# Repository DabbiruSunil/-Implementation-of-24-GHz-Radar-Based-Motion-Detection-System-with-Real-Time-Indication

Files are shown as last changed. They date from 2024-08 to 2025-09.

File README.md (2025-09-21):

# 📡 24-GHz Radar-Based Motion Detection System with Real-Time Indication

This repository contains the design, development, and testing files for a **24-GHz radar-based motion detection system**, capable of detecting movement with high accuracy using real-time signal processing. The project integrates hardware (custom PCB with a 24-GHz radar module) and software (firmware, MATLAB analysis, and signal processing algorithms) into a complete working system.

---

## 📌 Project Overview

The objective of this project is to build a **precise motion detection system** leveraging a **24-GHz radar sensor**. The radar signals are captured, digitized, and processed in real time to provide immediate feedback when motion is detected.

### Hardware

* Custom PCB designed in **KiCad**.
* Integration of **24-GHz radar module**, **ADC**, **DAC**, and **DMA** for efficient data handling.
* Gerber files provided for fabrication.

### Software

* **Firmware** written in **PSoC Creator** for the Cypress PSoC 5LP microcontroller.
* State machine–based design for efficient real-time processing.
* **MATLAB scripts** for radar data analysis and Discrete Fourier Transform (DFT)–based signal evaluation.

---

## ✨ Features

* **High-frequency motion detection** at 24 GHz.
* **Custom PCB** with modular radar integration.
* **Real-time indication** of detected motion.
* **Efficient data processing pipeline** using DMA and microcontroller firmware.
* **MATLAB support** for offline data visualization and spectral analysis.

---

## 📂 Repository Contents

* **`24GHz-Radar for movement Detection.pptx`** – Presentation of design, implementation, and performance.
* **`Gerber files for PCB.zip`** – Fabrication files for the custom PCB.
* **`KiCad files for PCB.zip`** – Full KiCad project for PCB layout and schematic.
* **`PSoC_project.zip`** – Source code, configuration, and firmware project for PSoC Creator.

---

## 🛠️ Getting Started

### 🔧 Prerequisites

* [KiCad](https://www.kicad.org/) – For PCB design files.
* [PSoC Creator](https://www.cypress.com/products/psoc-creator-integrated-design-environment-ide) – To build and flash firmware onto the PSoC 5LP.
* [MATLAB](https://www.mathworks.com/products/matlab.html) – For radar data analysis and signal processing.
* PCB fabrication service – To manufacture the board from the Gerber files.

### ⚙️ Installation & Usage

#### 1. PCB Design

* Open KiCad project files.
* Review or modify the layout.
* Send **Gerber files** to a PCB manufacturer.

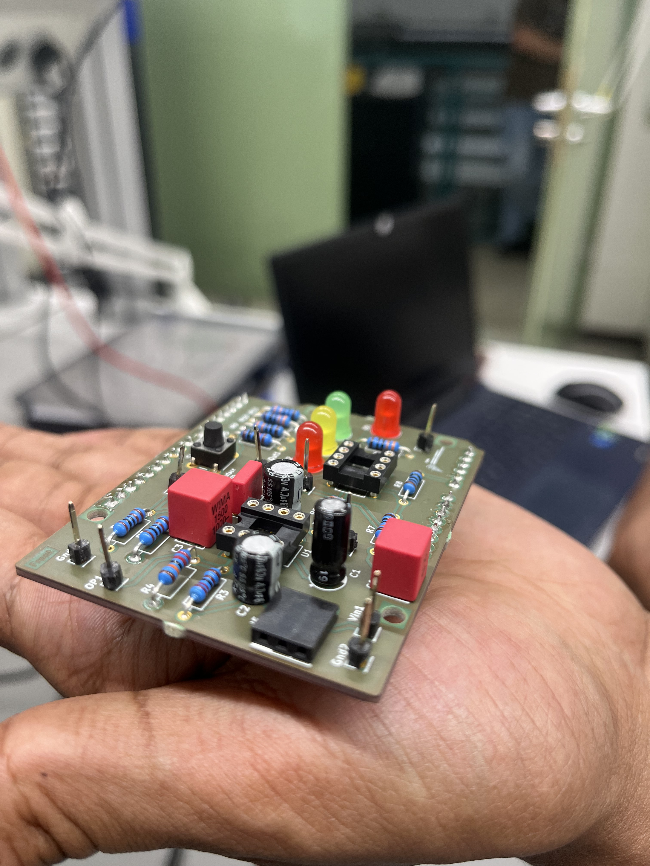
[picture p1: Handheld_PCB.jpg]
Handheld PCB
  

#### 2. Firmware Development

* Open the **PSoC project** in PSoC Creator.
* Compile and program the PSoC 5LP microcontroller.

#### 3. Signal Processing

* Use MATLAB scripts to process captured radar data.
* Perform **DFT analysis** for precise motion detection.

---

## 🧪 Testing & Validation

* Hardware validated through PCB prototypes.
* Firmware tested with real-time motion detection scenarios.
* MATLAB used to visualize motion profiles and confirm radar accuracy.

---

## 🤝 Contributing

Contributions are welcome! To propose improvements:

1. Fork this repository.
2. Create a feature branch.
3. Commit your changes.
4. Submit a pull request with details.

---

## 📜 License

MIT License – see [LICENSE](LICENSE) for details.

**Author:** Sunil Dabbiru

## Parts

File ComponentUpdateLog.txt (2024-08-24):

Last Modified Date & Time: 07/13/2024 11:51:06

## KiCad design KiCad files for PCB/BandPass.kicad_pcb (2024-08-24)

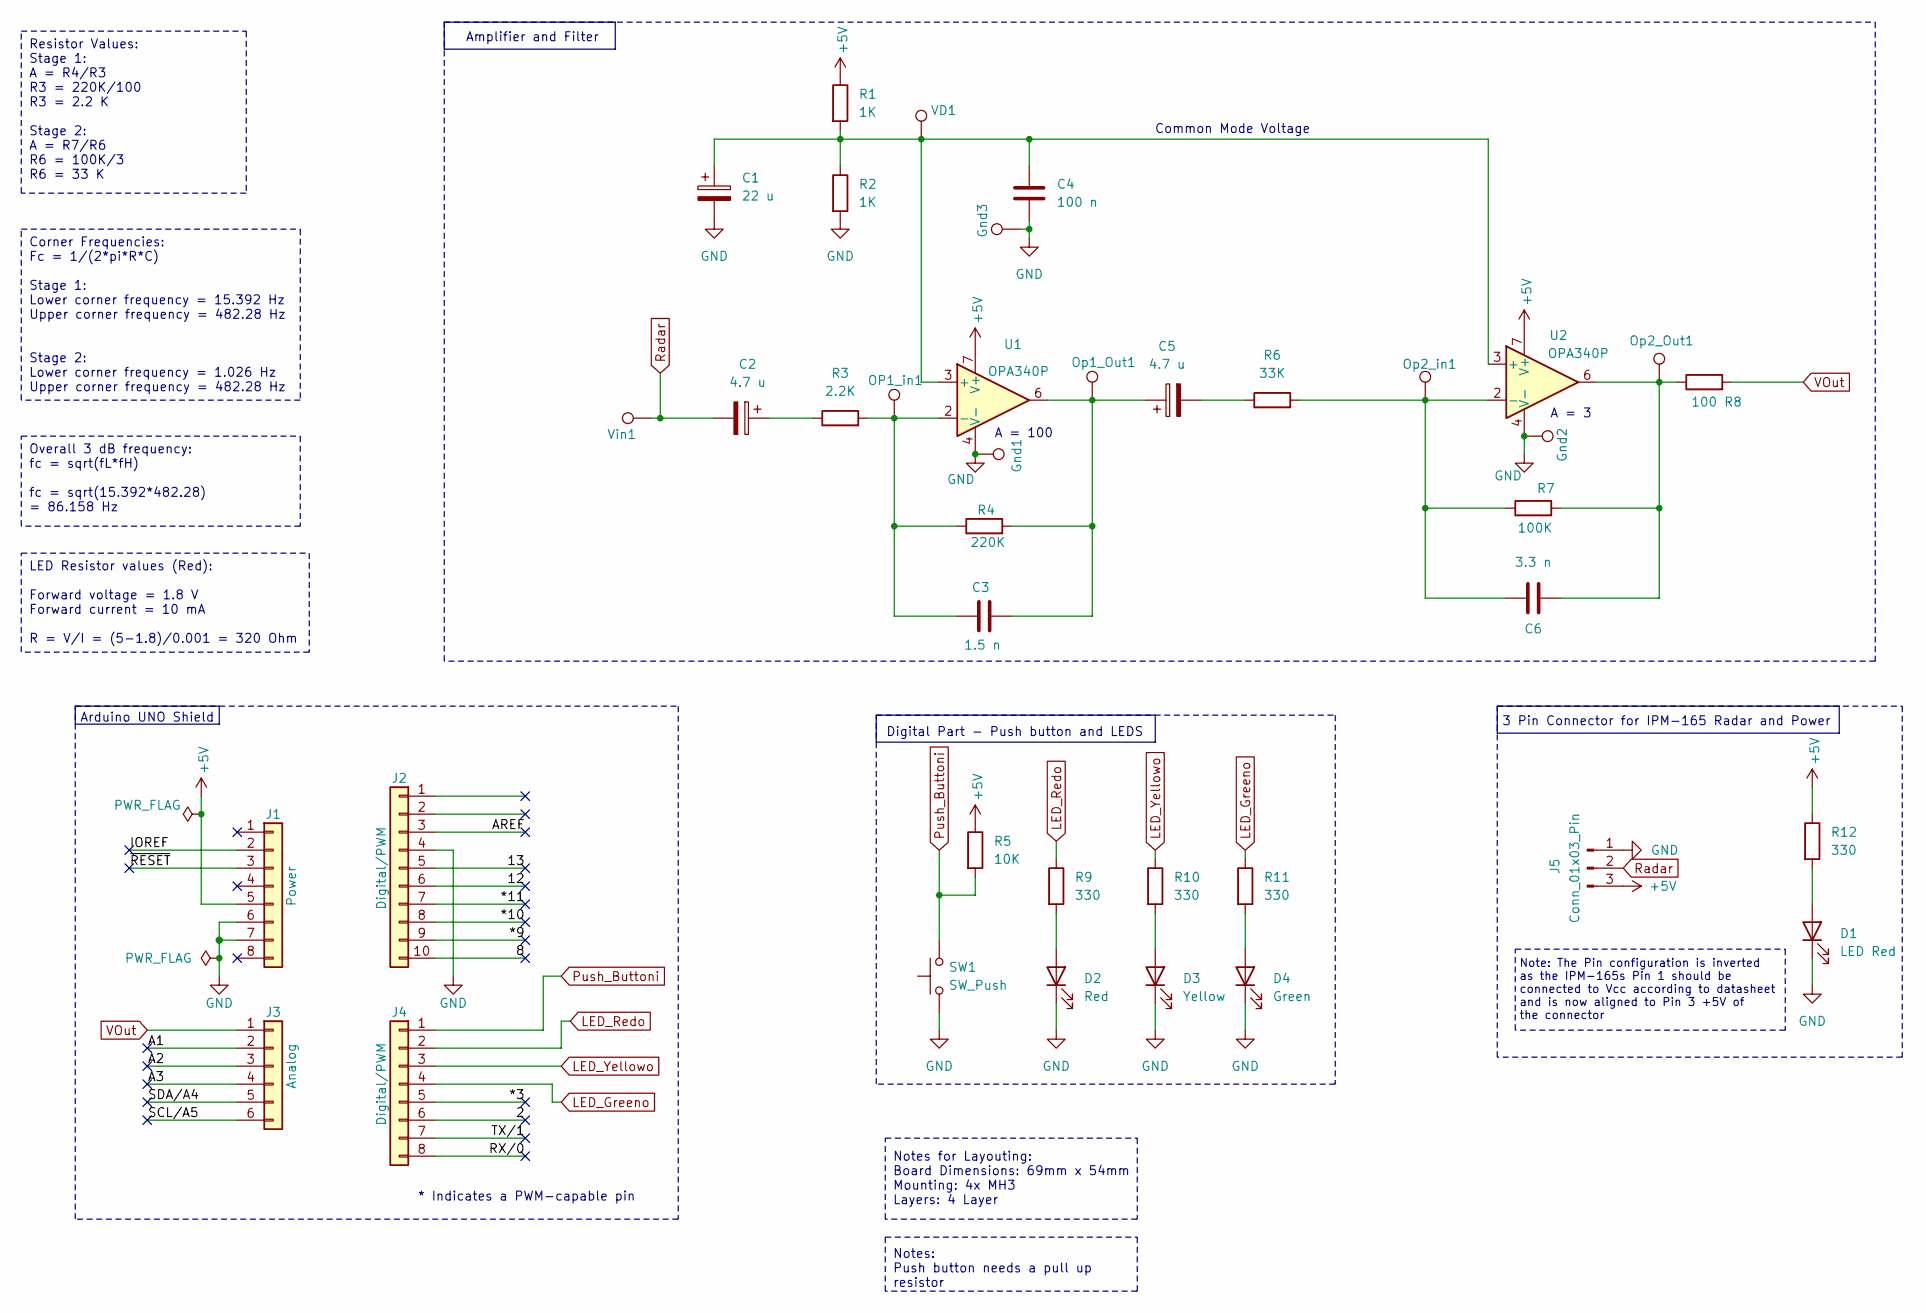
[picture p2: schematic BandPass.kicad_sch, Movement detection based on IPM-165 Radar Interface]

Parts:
C1: 22 u; CP_Radial_D5.0mm_P2.00mm
C2, C5: 4.7 u; CP_Radial_D5.0mm_P2.00mm
C3: 1.5 n; C_Rect_L7.2mm_W4.5mm_P5.00mm_FKS2_FKP2_MKS2_MKP2
C4: 100 n; C_Rect_L7.2mm_W3.0mm_P5.00mm_FKS2_FKP2_MKS2_MKP2
C6: 3.3 n; C_Rect_L7.2mm_W4.5mm_P5.00mm_FKS2_FKP2_MKS2_MKP2
D1: LED Red; LED_D5.0mm
D2: Red; LED_D5.0mm
D3: Yellow; LED_D5.0mm
D4: Green; LED_D5.0mm
Gnd1, Gnd2, Gnd3: Gnd; PinHeader_1x01_P2.54mm_Vertical
J1: Power; PinHeader_1x08_P2.54mm_Vertical
J2: Digital/PWM; PinHeader_1x10_P2.54mm_Vertical
J3: Analog; PinHeader_1x06_P2.54mm_Vertical
J4: Digital/PWM; PinHeader_1x08_P2.54mm_Vertical
J5: Conn_01x03_Pin; PinSocket_1x03_P2.54mm_Horizontal
OP1_in1: OP1_In; PinHeader_1x01_P2.54mm_Vertical
Op1_Out1: OP1_Out; PinHeader_1x01_P2.54mm_Vertical
Op2_Out1: OP2_out; PinHeader_1x01_P2.54mm_Vertical
Op2_in1: OP2_In; PinHeader_1x01_P2.54mm_Vertical
R1, R2: 1K; R_Axial_DIN0207_L6.3mm_D2.5mm_P10.16mm_Horizontal
R3: 2.2K; R_Axial_DIN0207_L6.3mm_D2.5mm_P10.16mm_Horizontal
R4: 220K; R_Axial_DIN0207_L6.3mm_D2.5mm_P10.16mm_Horizontal
R5: 10K; R_Axial_DIN0207_L6.3mm_D2.5mm_P10.16mm_Horizontal
R6: 33K; R_Axial_DIN0207_L6.3mm_D2.5mm_P10.16mm_Horizontal
R7: 100K; R_Axial_DIN0207_L6.3mm_D2.5mm_P10.16mm_Horizontal
R8: 100; R_Axial_DIN0207_L6.3mm_D2.5mm_P10.16mm_Horizontal
R9, R10, R11, R12: 330; R_Axial_DIN0207_L6.3mm_D2.5mm_P10.16mm_Horizontal
SW1: SW_Push; SW_PUSH_6mm_H7.3mm
U1, U2: OPA340P; DIP-8_W7.62mm
VD1: Voltage Divider; PinHeader_1x01_P2.54mm_Vertical
Vin1: Vin; PinHeader_1x01_P2.54mm_Vertical

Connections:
+5V: J1.5, J5.3, R1.1, R5.1, R12.1, U1.7 (V+), U2.7 (V+)
/2: J4.6
/8: J2.10
/12: J2.6
/13: J2.5
/*3: J4.5
/*9: J2.9
/*10: J2.8
/*11: J2.7
/A1: J3.2
/A2: J3.3
/A3: J3.4
/AREF: J2.3
/IOREF: J1.2
/RX/0: J4.8
/SCL/A5: J3.6
/SDA/A4: J3.5
/TX/1: J4.7
/~RESET: J1.3
GND: C1.2, C4.2, D1.1 (K), D2.1 (K), D3.1 (K), D4.1 (K), Gnd1.1, Gnd2.1, Gnd3.1, J1.6, J1.7, J2.4, J5.1, R2.2, SW1.1, U1.4 (V-), U2.4 (V-)
LED_Greeno: J4.4, R11.1
LED_Redo: J4.2, R9.1
LED_Yellowo: J4.3, R10.1
unnamed: C2.1, R3.1
unnamed: C3.2, C5.1, Op1_Out1.1, R4.2, U1.6
unnamed: C5.2, R6.1
unnamed: C6.2, Op2_Out1.1, R7.2, R8.1, U2.6
unnamed: D1.2 (A), R12.2
unnamed: D2.2 (A), R9.2
unnamed: D3.2 (A), R10.2
unnamed: D4.2 (A), R11.2
unnamed: C1.1, C4.1, R1.2, R2.1, U1.3 (+), U2.3 (+), VD1.1
unnamed: C3.1, OP1_in1.1, R3.2, R4.1, U1.2 (-)
unnamed: C6.1, Op2_in1.1, R6.2, R7.1, U2.2 (-)
Push_Buttoni: J4.1, R5.2, SW1.2
Radar: C2.2, J5.2, Vin1.1
VOut: J3.1, R8.2

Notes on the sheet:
Corner Frequencies: Fc = 1/(2*pi*R*C) Stage 1: Lower corner frequency = 15.392 Hz Upper corner frequency = 482.28 Hz Stage 2: Lower corner frequency = 1.026 Hz Upper corner frequency = 482.28 Hz
Resistor Values: Stage 1: A = R4/R3 R3 = 220K/100 R3 = 2.2 K Stage 2: A = R7/R6 R6 = 100K/3 R6 = 33 K
Overall 3 dB frequency: fc = sqrt(fL*fH) fc = sqrt(15.392*482.28) = 86.158 Hz
LED Resistor values (Red): Forward voltage = 1.8 V Forward current = 10 mA R = V/I = (5-1.8)/0.001 = 320 Ohm
Notes for Layouting: Board Dimensions: 69mm x 54mm Mounting: 4x MH3 Layers: 4 Layer
3 Pin Connector for IPM-165 Radar and Power
Digital Part - Push button and LEDS
Notes: Push button needs a pull up resistor
Arduino UNO Shield
Amplifier and Filter
* Indicates a PWM-capable pin
Common Mode Voltage
A = 100
Note: The Pin configuration is inverted as the IPM-165s Pin 1 should be connected to Vcc according to datasheet and is now aligned to Pin 3 +5V of the connector
A = 3

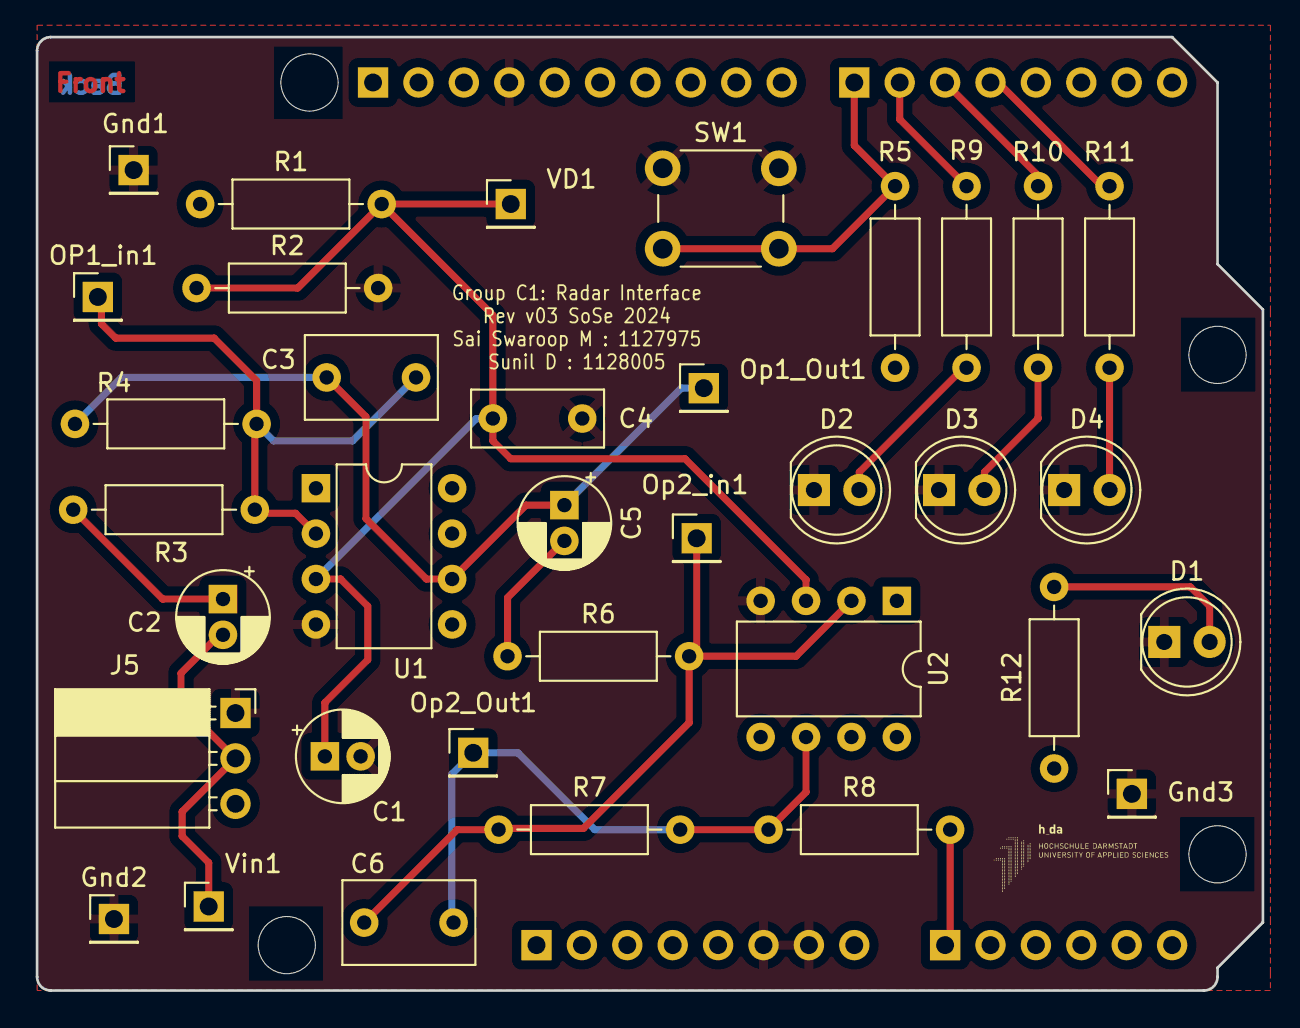
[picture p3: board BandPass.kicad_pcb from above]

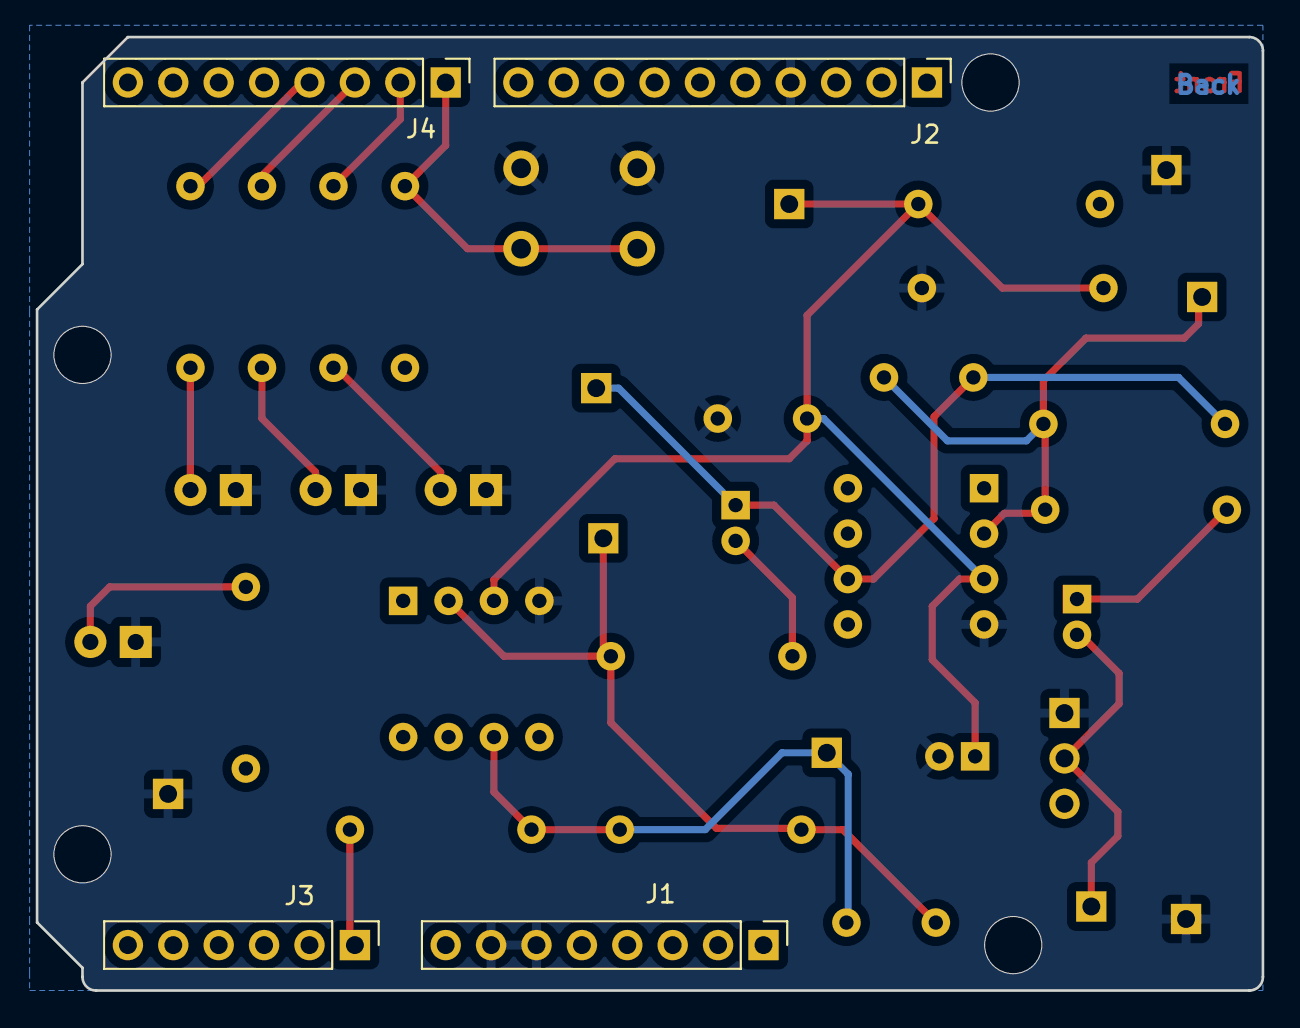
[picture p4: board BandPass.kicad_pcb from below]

Board: 4 copper layers, 68.6 x 53.3 mm, 43 parts (4 on the bottom side), 19 nets.

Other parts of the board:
MH1, MH2, MH3, MH4: MountingHole_3.2mm

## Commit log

2024-08-24 Add KiCAD files to repository
    [BandPass.kicad_pcb, BandPass.kicad_sch]
2024-08-24 Add Gerber fiiles to repository
    [BandPass-B_Cu.gbr, BandPass-B_Mask.gbr, BandPass-B_Silkscreen.gbr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]
